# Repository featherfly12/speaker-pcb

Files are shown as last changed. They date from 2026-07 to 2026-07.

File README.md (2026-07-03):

# Speaker PCB

In this github, there is a pcb design that has a total of 1 song!  

| Part | What it is | What it does in this circuit |
|---|---|---|
| STM32L433CCT6 | Microcontroller | Runs your code — reads the song from flash memory and streams it to the speaker amplifier over I2S |
| W25Q128JVEIQ | 16 MB flash memory chip | Stores the raw audio file (like a tiny solid-state drive) so the microcontroller can play it back |
| MAX98357AETE+T | I2S audio amplifier | Takes the digital audio stream from the microcontroller and amplifies it directly via pulse-width modulation (PWM) — rapid switching whose pulse widths track the signal, which the speaker smooths back into sound. This switching design is what makes it a class-D amplifier, and what lets it drive a speaker efficiently from such a small chip. |
| AP2112K-3.3TRG1 | 3.3V Low-dropout Regulator (LDO) | Steps down the input voltage to the stable 3.3V that the microcontroller and other chips need to operate safely. This can eliminate most noise from the power supply, making the 3.3V "clean" power. |
| SMAJ13A | TVS (transient voltage suppression) diode | Prevents voltage spikes on the power input. |
| PESD3V3L4UG,115 | 4-channel ESD protection array | Guards four signal lines at once against static electricity (ESD). Static can silently kill chips when you touch their pins!  |
| PESD3V3L1BA | Single-channel ESD protection diode | Same idea as above, but for one signal line.|
|ECS-80-12-33-JGN-TR | 8MHz Crystal | A crystal that oscillates within 20 ppm of 8MHz when driven by the MCU (with some helper capacitors). This makes the clock of the MCU much more precise, and prevents the frequency of the song from drifting while it is playing. |

## Programming the Board
Music from an MP3 file is converted into pure binary 16-bit data at 31.25kHz using scripts in `firmware/media`. The output, `media.bin`, may be flashed onto the chip using an external loader and [STM32CubeProgrammer](https://www.st.com/en/development-tools/stm32cubeprog.html). The external loader for this custom PCB was written in the folder `firmware/W25Q128_HAL`, and the actual compiled loader file is  `W25Q128_STM32L433_HAL.stldr`. Once the external memory is programmed with the song, the STM32 itself can be flashed with the `music_player` project using [STM32CubeIDE](https://www.st.com/en/development-tools/stm32cubeide.html). 

These programs were written with the help of Claude Code / Sonnet 4.6.

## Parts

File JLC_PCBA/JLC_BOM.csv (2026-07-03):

Comment | Designator | Footprint | JLC Part #
22uF | C1,C16 | Capacitor_SMD:C_1206_3216Metric_Pad1.33x1.80mm_HandSolder | C12891
18pF | C2,C3 | Capacitor_SMD:C_0402_1005Metric_Pad0.74x0.62mm_HandSolder | C1549
0.1uF | C4,C5,C9,C10,C11,C13,C15,C21,C22,C23 | Capacitor_SMD:C_0603_1608Metric_Pad1.08x0.95mm_HandSolder | C14663
4.7uF | C6 | Capacitor_SMD:C_1206_3216Metric_Pad1.33x1.80mm_HandSolder | C29823
10nF | C7 | Capacitor_SMD:C_0805_2012Metric_Pad1.18x1.45mm_HandSolder | C1710
1uF | C8,C19,C20 | Capacitor_SMD:C_0603_1608Metric_Pad1.08x0.95mm_HandSolder | C15849
10uF | C14,C18 | Capacitor_SMD:C_1206_3216Metric_Pad1.33x1.80mm_HandSolder | C13585
SMAJ13A | D1 | project_footprints:DIONM5126X250N | C148214
PESD3V3L4UG,115 | D2 | project_footprints:PESD3V3L4UG115 | C70500
PESD3V3L1BA | D3 | Diode_SMD:D_SOD-323_HandSoldering | C2687129
10k | R1,R2,R12,R13,R14,R15 | Resistor_SMD:R_1206_3216Metric_Pad1.30x1.75mm_HandSolder | C17902
33 | R3,R4,R5,R6,R7,R8,R9,R10,R11 | Resistor_SMD:R_0603_1608Metric_Pad0.98x0.95mm_HandSolder | C23140
STM32L433CCT6 | U1 | project_footprints:QFP50P900X900X160-48N | C110061
W25Q128JVEIQ | U2 | project_footprints:WSON_128JVEIQ_WIN-M | C2456297
MAX98357AETE+T | U3 | project_footprints:21-0136I_T1633-4_MXM-M | C910544

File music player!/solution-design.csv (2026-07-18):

Reference | Qty | Value | DNP | Exclude from BOM | Exclude from Board | Footprint | Datasheet | MFG #
C2,C3 | 2 | 18pF |  |  |  | Capacitor_SMD:C_0402_1005Metric_Pad0.74x0.62mm_HandSolder
C4,C5,C9,C10,C11,C13,C15,C21,C22,C23 | 10 | 0.1uF |  |  |  | Capacitor_SMD:C_0603_1608Metric_Pad1.08x0.95mm_HandSolder
C6 | 1 | 4.7uF |  |  |  | Capacitor_SMD:C_1206_3216Metric_Pad1.33x1.80mm_HandSolder
C7 | 1 | 10nF |  |  |  | Capacitor_SMD:C_0805_2012Metric_Pad1.18x1.45mm_HandSolder
C8,C19,C20 | 3 | 1uF |  |  |  | Capacitor_SMD:C_0603_1608Metric_Pad1.08x0.95mm_HandSolder
C12 | 1 | 220uF |  |  |  | Capacitor_THT:CP_Radial_D10.0mm_P5.00mm
C14,C18 | 2 | 10uF |  |  |  | Capacitor_SMD:C_1206_3216Metric_Pad1.33x1.80mm_HandSolder
C16,C17 | 2 | 22uF |  |  |  | Capacitor_SMD:C_1210_3225Metric_Pad1.33x2.70mm_HandSolder
D1 | 1 | SMAJ13A |  |  |  | project_footprints:DIONM5126X250N | https://componentsearchengine.com/Datasheets/2/SMAJ13A.pdf
D2 | 1 | PESD3V3L4UG,115 |  |  |  | project_footprints:PESD3V3L4UG115 | https://assets.nexperia.com/documents/data-sheet/PESDXL4UF_G_W.pdf
D3 | 1 | PESD3V3L1BA |  |  |  | Diode_SMD:D_SOD-323_HandSoldering | https://assets.nexperia.com/documents/data-sheet/PESDXL5UF_V_Y.pdf
J2 | 1 | PJ-002AH |  |  |  | project_footprints:CUI_PJ-002AH
L1 | 1 | 4.7uH |  |  |  | project_footprints:IND_NRS6028T0R9NMGJV_TAY | https://mm.digikey.com/Volume0/opasdata/d220001/medias/docus/664/NRS6028T4R7MMGKV_SS.pdf | NRS6028T4R7MMGKV
LS1 | 1 | Speaker |  |  |  | project_footprints:CES-46257-24-L200 | https://www.sameskydevices.com/product/resource/digikeypdf/ces-46257-24-l200.pdf
R1,R2,R12,R13,R14,R15 | 6 | 10k |  |  |  | Resistor_SMD:R_1206_3216Metric_Pad1.30x1.75mm_HandSolder
R3,R4,R5,R6,R7,R8,R9,R10,R11 | 9 | 33 |  |  |  | Resistor_SMD:R_0603_1608Metric_Pad0.98x0.95mm_HandSolder
R16 | 1 | 3362P-1-502LF |  |  |  | project_footprints:POT_3362P | 3362P-1-502LF
S1 | 1 | Switch |  |  |  | project_footprints:PTS647SK70SMTR2LFS | https://www.ckswitches.com/media/2567/pts647.pdf | PTS647SM70SMTR2 LFS
U1 | 1 | STM32L433CCT6 |  |  |  | project_footprints:QFP50P900X900X160-48N
U2 | 1 | W25Q128JVEIQ |  |  |  | project_footprints:WSON_128JVEIQ_WIN-M | W25Q128JVEIQ
U3 | 1 | MAX98357AETE+T |  |  |  | project_footprints:21-0136I_T1633-4_MXM-M | MAX98357AETE+T
U4 | 1 | AP63205WU-7 |  |  |  | project_footprints:SOIC_05WU-7_DIO-M | AP63205WU-7
U5 | 1 | AP2112K-3.3TRG1 |  |  |  | project_footprints:SOT_RG1_DIO-M | AP2112K-3.3TRG1
Y1 | 1 | ABS07-32.768KHZ-T |  |  |  | project_footprints:CAP_ABS07-32.768KHZ-T_ABR-M | ABS07-32.768KHZ-T

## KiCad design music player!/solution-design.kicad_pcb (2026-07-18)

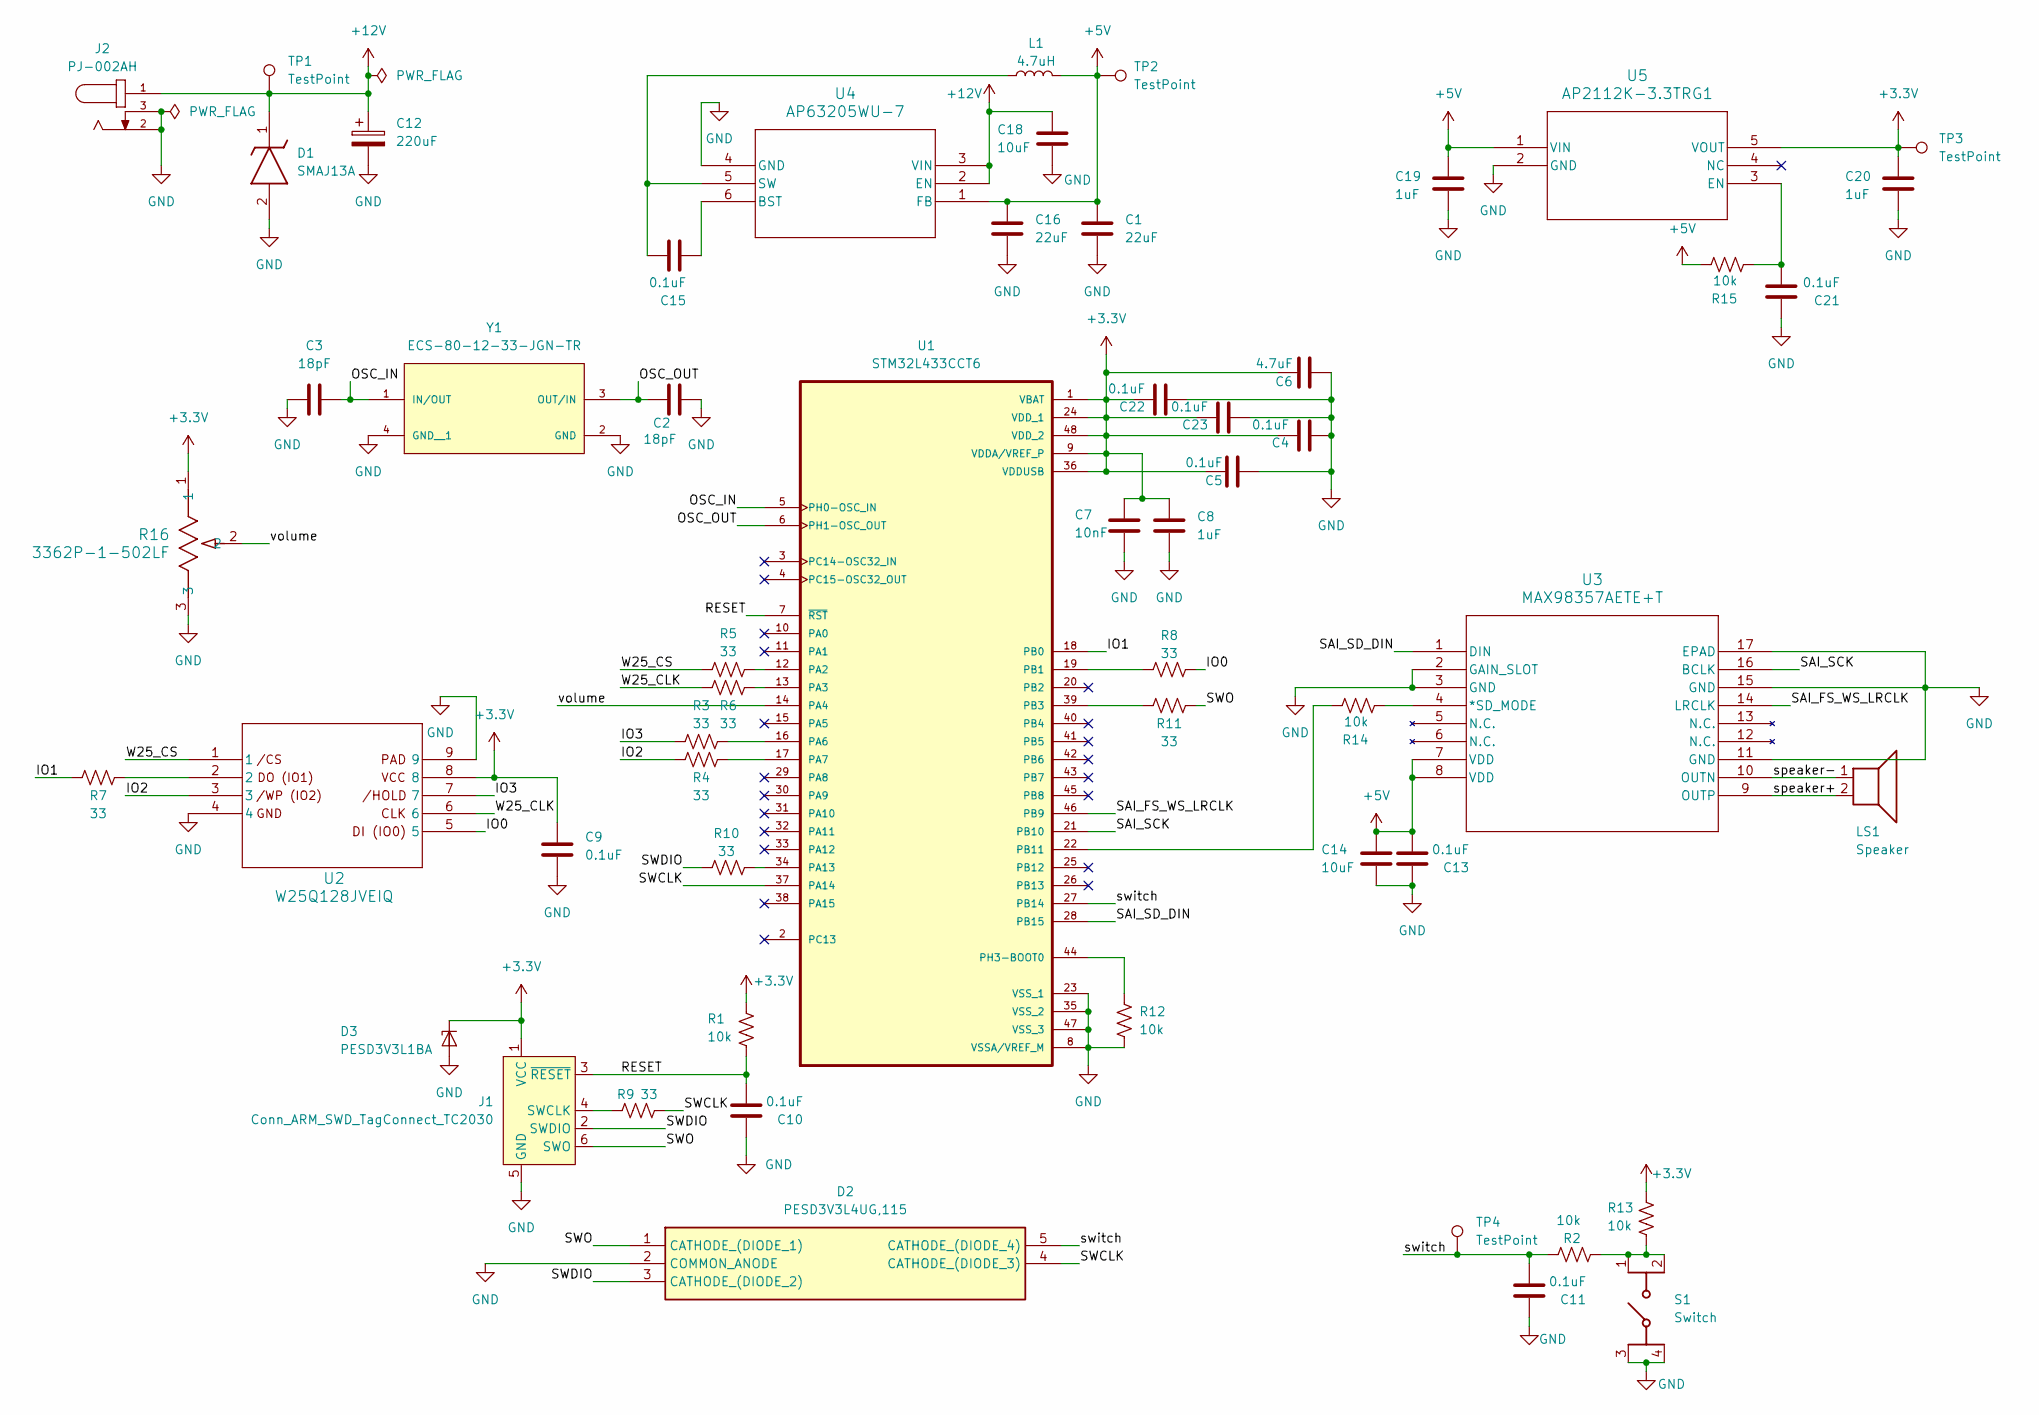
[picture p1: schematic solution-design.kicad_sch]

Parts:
C1, C16: 22uF; C_1206_3216Metric_Pad1.33x1.80mm_HandSolder; JLC Part # C12891
C2, C3: 18pF; C_0402_1005Metric_Pad0.74x0.62mm_HandSolder; JLC Part # C1549
C4, C5, C9, C10, C11, C13, C15, C21, C22, C23: 0.1uF; C_0603_1608Metric_Pad1.08x0.95mm_HandSolder; JLC Part # C14663
C6: 4.7uF; C_1206_3216Metric_Pad1.33x1.80mm_HandSolder; JLC Part # C29823
C7: 10nF; C_0805_2012Metric_Pad1.18x1.45mm_HandSolder; JLC Part # C1710
C8, C19, C20: 1uF; C_0603_1608Metric_Pad1.08x0.95mm_HandSolder; JLC Part # C15849
C12: 220uF; CP_Radial_D10.0mm_P5.00mm
C14, C18: 10uF; C_1206_3216Metric_Pad1.33x1.80mm_HandSolder; JLC Part # C13585
D1: SMAJ13A; DIONM5126X250N; Mouser Part Number 576-SMAJ13A
D2: PESD3V3L4UG,115; PESD3V3L4UG115; Mouser Part Number 771-PESD3V3L4UG-T/R
D3: PESD3V3L1BA; D_SOD-323_HandSoldering; MFG # PESD3V3L1BA; JLC Part # C2687129
J1: Conn_ARM_SWD_TagConnect_TC2030; Tag-Connect_TC2030-IDC-FP_2x03_P1.27mm_Vertical
J2: PJ-002AH; CUI_PJ-002AH
L1: 4.7uH; IND_NRS6028T0R9NMGJV_TAY; MFG # NRS6028T4R7MMGKV
LS1: Speaker; CES-46257-24-L200
R1, R2, R12, R13, R14, R15: 10k; R_1206_3216Metric_Pad1.30x1.75mm_HandSolder; JLC Part # C17902
R3, R4, R5, R6, R7, R8, R9, R10, R11: 33; R_0603_1608Metric_Pad0.98x0.95mm_HandSolder; JLC # C23140
R16: 3362P-1-502LF; POT_3362P
S1: Switch; PTS647SK70SMTR2LFS; MFG # PTS647SM70SMTR2 LFS
TP1, TP2, TP3: TestPoint; TestPoint_Loop_D2.54mm_Drill1.5mm_Beaded
TP4: TestPoint; TestPoint_Loop_D1.80mm_Drill1.0mm_Beaded
U1: STM32L433CCT6; QFP50P900X900X160-48N; MFG # STM32L433CCT6; JLC Part # C110061
U2: W25Q128JVEIQ; WSON_128JVEIQ_WIN-M; MFG # W25Q128JVEIQ; JLC Part # C2456297
U3: MAX98357AETE+T; 21-0136I_T1633-4_MXM-M; MFG # MAX98357AETE+T; JLC Part # C910544
U4: AP63205WU-7; SOIC_05WU-7_DIO-M
U5: AP2112K-3.3TRG1; SOT_RG1_DIO-M
Y1: ECS-80-12-33-JGN-TR; XTAL_ECS-240-8-33-AGN-TR

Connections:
+3.3V: C4.1, C5.1, C6.1, C7.1, C8.1, C9.2, C20.1, C22.1, C23.1, D3.1 (K1), J1.1 (VCC), R1.1, R13.2, R16.1, TP3.1 (1_1), U1.1 (VBAT), U1.9 (VDDA/VREF_P), U1.24 (VDD_1), U1.36 (VDDUSB), U1.48 (VDD_2), U2.8, U5.5 (VOUT)
+5V: C1.1, C13.1, C14.1, C16.1, C19.1, L1.2, R15.1, TP2.1 (1_1), U3.7 (VDD), U3.8 (VDD), U4.1 (FB), U5.1 (VIN)
+12V: C12.1, C18.1, D1.1 (K), J2.1, TP1.1 (1_1), U4.2 (EN), U4.3 (VIN)
/IO0: R8.2, U2.5
/IO1: R7.1, U1.18 (PB0)
/IO2: R4.1, U2.3
/IO3: R3.1, U2.7
/OSC_IN: C3.2, U1.5 (PH0-OSC_IN), Y1.1 (IN/OUT)
/OSC_OUT: C2.2, U1.6 (PH1-OSC_OUT), Y1.3 (OUT/IN)
/RESET: C10.1, J1.3 (~RESET), R1.2, U1.7 (~RST)
/SAI_FS_WS_LRCLK: U1.46 (PB9), U3.14 (LRCLK)
/SAI_SCK: U1.21 (PB10), U3.16 (BCLK)
/SAI_SD_DIN: U1.28 (PB15), U3.1 (DIN)
/SWCLK: D2.4 (CATHODE_(DIODE_3)), R9.2, U1.37 (PA14)
/SWDIO: D2.3 (CATHODE_(DIODE_2)), J1.2 (SWDIO), R10.1
/SWO: D2.1 (CATHODE_(DIODE_1)), J1.6 (SWO), R11.2
/W25_CLK: R6.1, U2.6
/W25_CS: R5.1, U2.1
/speaker+: LS1.2, U3.9 (OUTP)
/speaker-: LS1.1, U3.10 (OUTN)
/switch: C11.1, D2.5 (CATHODE_(DIODE_4)), R2.1, TP4.1 (1_1), U1.27 (PB14)
/volume: R16.2, U1.14 (PA4)
GND: C1.2, C2.1, C3.1, C4.2, C5.2, C6.2, C7.2, C8.2, C9.1, C10.2, C11.2, C12.2, C13.2, C14.2, C16.2, C18.2, C19.2, C20.2, C21.2, C22.2, C23.2, D1.2 (A), D2.2 (COMMON_ANODE), D3.2 (A), J1.5 (GND), J2.2, J2.3, R12.2, R16.3, S1.3 (COM_1), S1.4 (COM_2), U1.8 (VSSA/VREF_M), U1.23 (VSS_1), U1.35 (VSS_2), U1.47 (VSS_3), U2.4, U2.9, U3.2 (GAIN_SLOT), U3.3 (GND), U3.11 (GND), U3.15 (GND), U3.17 (EPAD), U4.4 (GND), U5.2 (GND), Y1.2 (GND), Y1.4 (GND__1)
unnamed: J1.4 (SWCLK), R9.1
unnamed: R7.2, U2.2
unnamed: R2.2, R13.1, S1.1 (NO_1), S1.2 (NO_2)
unnamed: R5.2, U1.12 (PA2)
unnamed: R6.2, U1.13 (PA3)
unnamed: R3.2, U1.16 (PA6)
unnamed: R4.2, U1.17 (PA7)
unnamed: R10.2, U1.34 (PA13)
unnamed: R8.1, U1.19 (PB1)
unnamed: R11.1, U1.39 (PB3)
unnamed: R14.1, U1.22 (PB11)
unnamed: R12.1, U1.44 (PH3-BOOT0)
unnamed: R14.2, U3.4 (*SD_MODE)
unnamed: C15.2, U4.6 (BST)
unnamed: C15.1, L1.1, U4.5 (SW)
unnamed: C21.1, R15.2, U5.3 (EN)

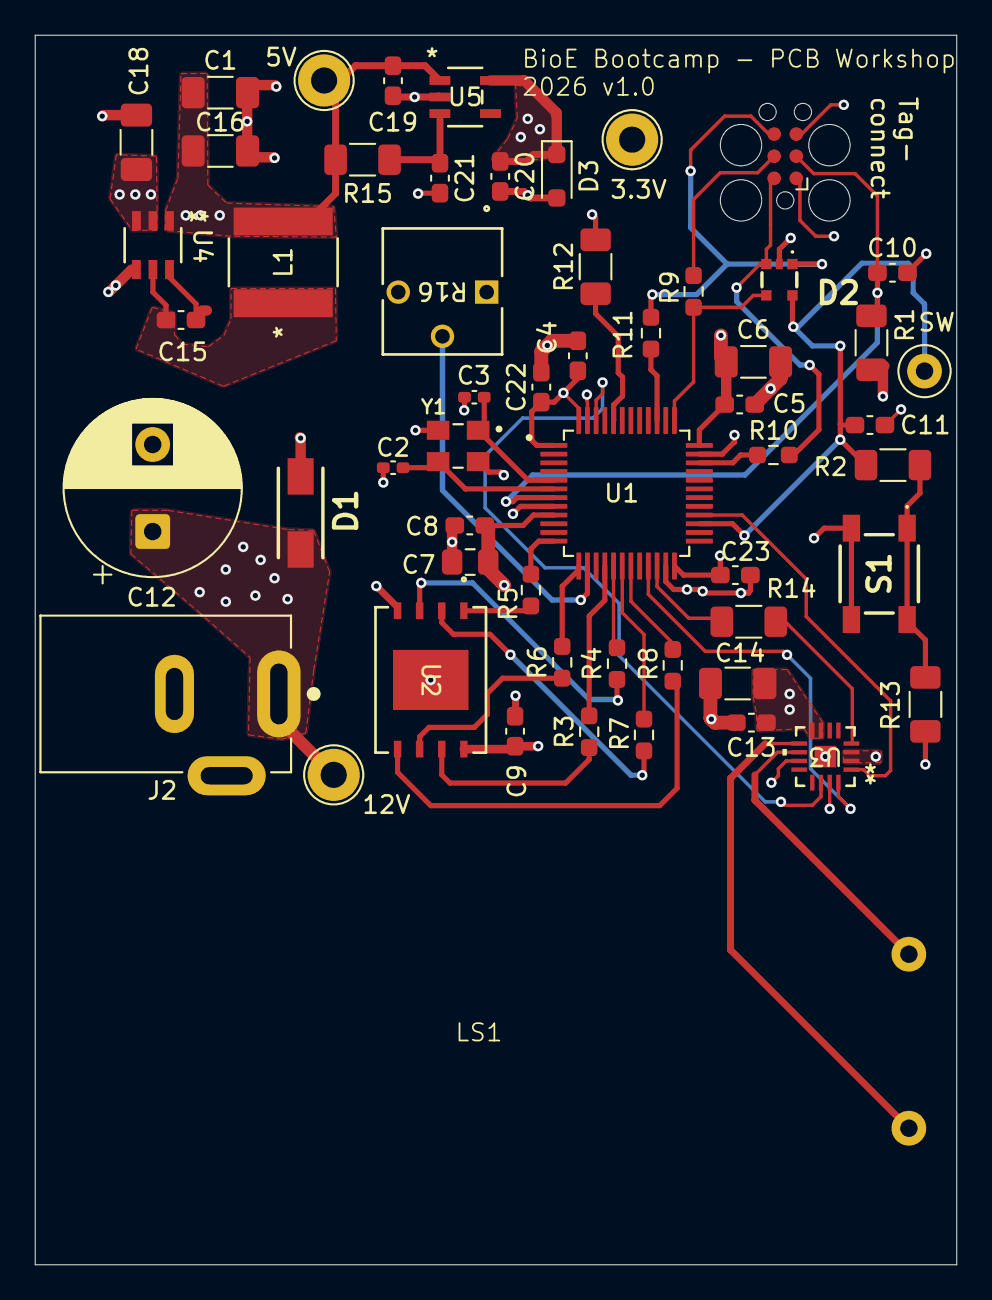
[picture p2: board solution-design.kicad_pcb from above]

Board: 4 copper layers, 52.9 x 70.7 mm, 56 parts (0 on the bottom side), 39 nets.
